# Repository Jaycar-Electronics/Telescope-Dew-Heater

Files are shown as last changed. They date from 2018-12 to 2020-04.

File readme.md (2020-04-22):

# Telescope Dew Heater

This project brings together a few Duinotech Modules and some other parts to create a versatile tool. Inspired by the Dew Heaters used on telescopes, it senses ambient temperature and humidity to control a small heater. Not just for telescopes, but anything that needs to avoid condensation.

## Features include:
- Programmable temperature setpoint
- Temperature target can be set above ambient or dewpoint
- Settings can be saved to EEPROM
- Adjustable failsafe heater output to use if sensors are faulty
- Comprehensive LCD info screen

By making use of as much data as possible, the unit uses no more power than necessary, and can even be run straight from a USB battery pack. It can run a set number of degrees above either dewpoint or ambient temperature. The backlight intensity is also adjustable in code and we've even designed a 3d-printed enclosure that will practically turn it into a professional looking unit.

## Components

| Qty | Code | Description |
| --- | --- | --- |
| 1 | [XC4520](http://jaycar.com.au/p/XC4520) | Temperature and Humidity module |
| 1 | [XC4454](http://jaycar.com.au/p/XC4454) | LCD controller shield |
| 1 | [XC4410](http://jaycar.com.au/p/XC4410) | UNO main board |
| 1 | [RN3440](http://jaycar.com.au/p/RN3440) | 10K Thermistor |
| 1 | [RR0596](http://jaycar.com.au/p/RR0596) | 10K resistor |
| 1 | [RR0572](http://jaycar.com.au/p/RR0572) | 1K resistor |
| 1 | [ZT2468](http://jaycar.com.au/p/ZT2468) | MOSFET |
| 1 | [XC4482](http://jaycar.com.au/p/XC4482) | Proto shield |
| 1 | [WC6028](http://jaycar.com.au/p/WC6028) | Plug-socket lead |
| 1 | [RR3264](http://jaycar.com.au/p/RR3264) | 5W 390 resistor |

The 5W resistor is the heater element. For more power, even a RR3254 15Ohm resistor will happily run off most USB ports (up to 500mA), giving about 1.6 Watts. Another option is to run multiple resistors in parallel to distribute the heat better. For more power, a proper telescope heat band should be used. These usually use an RCA plug, so an RCA socket like PS0250 could be fitted. The circuit uses the VIN pin on the Proto Shield, which cannot handle more than about 1A of current.

## Assembly

Most of the assembly involves adding components to the Proto Shield to give it all the extra functionality it needs. There are effectively three subcircuits on the Proto Shield, one for the thermistor, and another for the humidity sensor and the third to drive a MOSFET for the heater.

The photos below give a guide as to one way to assemble it, but there is a small area (surrounded by a white rectangle) on the Proto Shield which has numerous 5V and GND connections and some short strips, making this an ideal spot to put all this together, especially to make the 5V and GND connections.

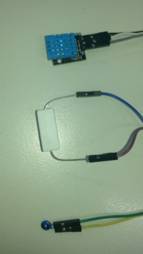
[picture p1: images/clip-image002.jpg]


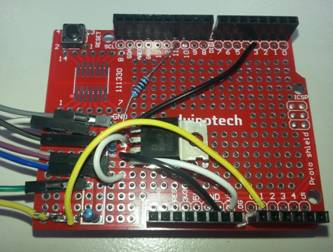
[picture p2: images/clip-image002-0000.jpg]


The thermistor subcircuit looks like this:



The yellow wire above goes to A1 and one of each of the resistor and thermistor, while the green wire goes to 5V, giving a simple voltage divider.



The top black wire connects the S pin of the module to D3.

The MOSFET circuit is the most complex:

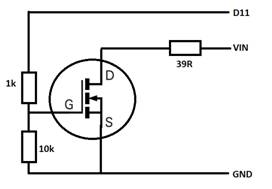
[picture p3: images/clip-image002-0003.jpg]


In the main photo above, the MOSFET's leads are G(gate), D(drain) and S(source), looking from top to bottom. The blue and purple wires run off the board to the 39R resistor, while the two white wires feed the 39R resistor from VIN and the MOSFET drain. The 10k resistor on the left ensures that the MOSFET is off unless the Uno is telling it to be on, while the 1k resistor provides a bit of isolation in case the MOSFET fails.

## Sketch

The code is quite lengthy and uses four different libraries. Luckily, only one of these needs to be installed, all the rest come with the Arduino IDE. The idDHT11 library reads the temperature and humidity sensor and also calculates the dew point. The file is Telescope_Dew_Heater.ino.

Before `setup()`, we initialise all the libraries and global variables. There is also a large array `temps[]` which stores the thermistor temperature conversion. For accuracy, all temperatures are calculated in tenths of a degree.

In setup, the LCD is initialised and values loaded from EEPROM. If these are valid, they are loaded into their respective variables. Because the DHT11 library does its readings in the background, we start a reading now for when we need one in `loop()`. Then we set the backlight intensity.

In `loop()`, the sketch reads all the input, including thermistor, DHT11 temperature, humidity and dew point and keypad. Then it responds to the keypad- if left is pressed, the heater works from the dew point temperature in 'D' mode, if the right button is presses, 'A' mode works with ambient temperature. The setpoint for the heater is set by the up and down buttons between zero and nine degrees. The select button allows the current settings to be saved in EEPROM. How long the button is held down determines what the default heater output will be if a sensor failure is detected.

The temperature target is calculated and the heater output is adjusted by changing the PWM on pin 11, then the current state is output is displayed. If an invalid reading is detected in either sensor, a message is displayed and the heater is set to the default output.

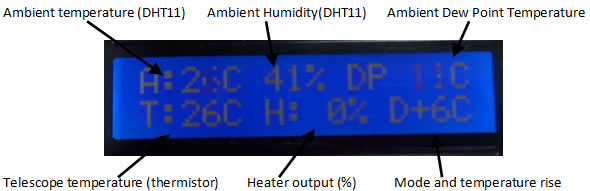
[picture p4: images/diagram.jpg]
screen diagram


In the above image, the ambient temperature is 26 degrees, but the dewpoint temperature is 11 degrees, so the heater will be aiming for dewpoint plus six degrees, or 17 degrees. The actual telescope temperature is 26 degrees, so the heater is off. If the heater was switched to ambient mode by pressing the right button, then the target would be 32 degrees, and the heater would turn fully on. In normal operation, the thermistor should be near, but not quite touching the heater resistor, so that it can quickly respond to changes.

## Improvements

There are a number of places where the heater could be improved, such as changing the default backlight setting to suit your application, or even making it one of the EEPROM settings. If you need more power, the recommended MOSFETs are capable of at least 5A at 24V. In that case, it would be recommended to run the power supply straight to the MOSFET circuit, and then feed VIN back to the UNO board. That way, the small PCB traces don't have to handle such a high current. An old laptop supply or 12V SLA could be options for this. As mentioned near the start, RCA sockets could be used to standardize the connections to those commonly used on heater bands.

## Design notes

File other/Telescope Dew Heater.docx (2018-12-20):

# Telescope Dew Heater

This project brings together a few Duinotech Modules and some other parts to create a versatile tool. Inspired by the Dew Heaters used on telescopes, it senses ambient temperature and humidity to control a small heater. Not just for telescopes, but anything that needs to avoid condensation.

Features include:

- Programmable temperature setpoint
- Temperature target can be set above ambient or dewpoint
- Settings can be saved to EEPROM
- Adjustable failsafe heater output to use if sensors are faulty
- Comprehensive LCD info screen

By making use of as much data as possible, the unit uses no more power than necessary, and can even be run straight from a USB battery pack. It can run a set number of degrees above either dewpoint or ambient temperature. The backlight intensity is also adjustable in code and we’ve even designed a 3d-printed enclosure that will practically turn it into a professional looking unit.

## Parts list:

XC4520 Temperature and Humidity Module

XC4454 LCD and Button Shield

XC4410 Duinotech Uno Board

RN3440 10K Thermistor

RR0596 10K resistors

RR0572 1K resistors

ZT2468 MOSFET (or even a XC4488 MOSFET module)

XC4482 Proto Shield

WC6028 Plug-socket leads

RR3264 5W 39Ohm Resistor

The 5W resistor is the heater element. For more power, even a RR3254 15Ohm resistor will happily run off most USB ports (up to 500mA), giving about 1.6 Watts. Another option is to run multiple resistors in parallel to distribute the heat better. For more power, a proper telescope heat band should be used. These usually use an RCA plug, so an RCA socket like PS0250 could be fitted. The circuit uses the VIN pin on the Proto Shield, which cannot handle more than about 1A of current.

## Assembly:

Most of the assembly involves adding components to the Proto Shield to give it all the extra functionality it needs. There are effectively three subcircuits on the Proto Shield, one for the thermistor, and another for the humidity sensor and the third to drive a MOSFET for the heater.

The photos below give a guide as to one way to assemble it, but there is a small area (surrounded by a white rectangle) on the Proto Shield which has numerous 5V and GND connections and some short strips, making this an ideal spot to put all this together, especially to make the 5V and GND connections.

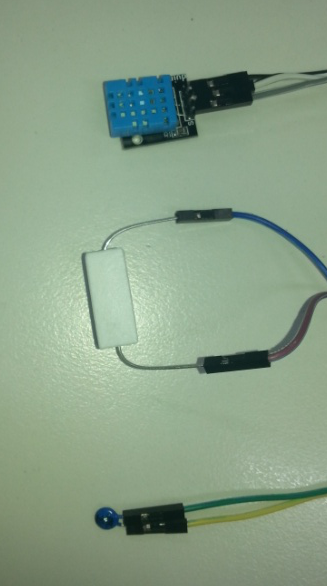
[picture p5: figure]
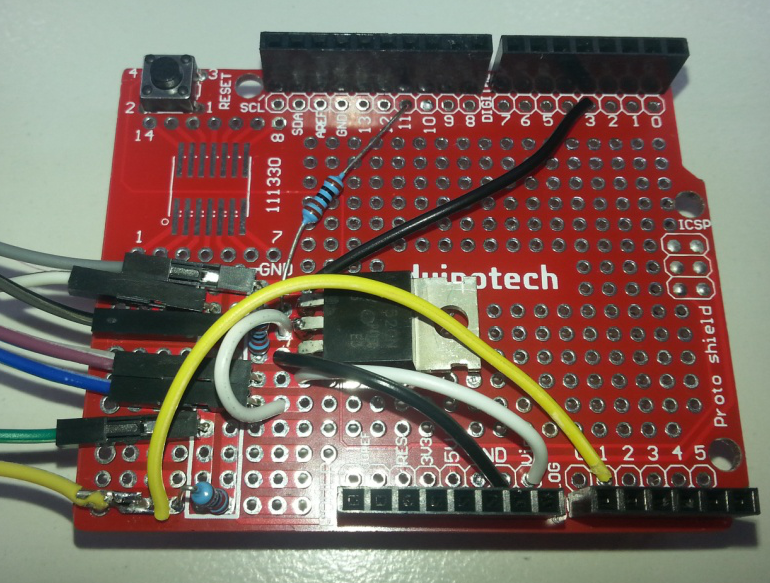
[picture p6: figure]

The thermistor subcircuit looks like this:

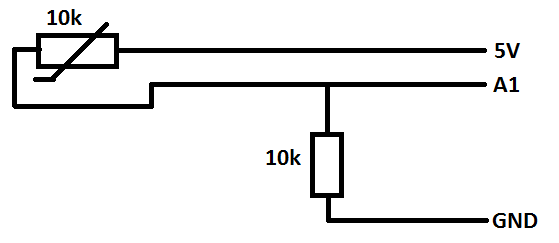
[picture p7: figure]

The yellow wire above goes to A1 and one end of each of the resistor and thermistor, while the green wire goes to 5V, giving a simple voltage divider.

The DHT11 Sensor subcircuit is even simpler:

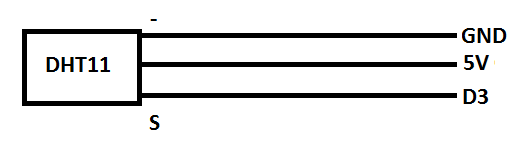
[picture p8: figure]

The top black wire connects the S pin of the module to D3.

The MOSFET circuit is the most complex:

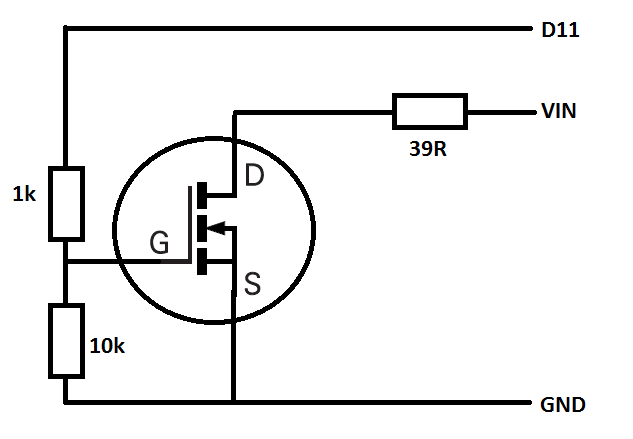
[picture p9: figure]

In the main photo above, the MOSFET’s leads are G(gate), D(drain) and S(source), looking from top to bottom. The blue and purple wires run off the board to the 39R resistor, while the two white wires feed the 39R resistor from VIN and the MOSFET drain. The 10k resistor on the left ensure that the MOSFET is off unless the Uno is telling it to be on, while the 1k resistor provides a bit of isolation in case the MOSFET fails.

## Sketch:

The code is quite lengthy and uses four different libraries. Luckily, only one of these needs to be installed, all the rest come with the Arduino IDE. The idDHT11 library reads the temperature and humidity sensor and also calculates the dew point. The file is Telescope_Dew_Heater.ino.

Before setup(), we initialise all the libraries and global variables. There is also a large array ‘temps[]’ which stores the thermistor temperature conversion. For accuracy, all temperatures are calculated in tenths of a degree.

In setup, the LCD is initialised and values loaded from EEPROM. If these are valid, they are loaded into their respective variables. Because the DHT11 library does its readings in the background, we start a reading now for when we need one in loop(). Then we set the backlight intensity.

In loop(), the sketch reads all the input, including thermistor, DHT11 temperature, humidity and dew point and keypad. Then it responds to the keypad- if left is pressed, the heater works from the dew point temperature in ‘D’ mode, if the right button is presses, ‘A’ mode works with ambient temperature. The setpoint for the heater is set by the up and down buttons between zero and nine degrees. The select button allows the current settings to be saved in EEPROM. How long the button is held down determines what the default heater output will be if a sensor failure is detected.

The temperature target is calculated and the heater output is adjusted by changing the PWM on pin 11, then the current state is output is displayed. If an invalid reading is detected in either sensor, a message is displayed and the heater is set to the default output.

Ambient temperature (DHT11) Ambient Humidity(DHT11) Ambient Dew Point Temperature

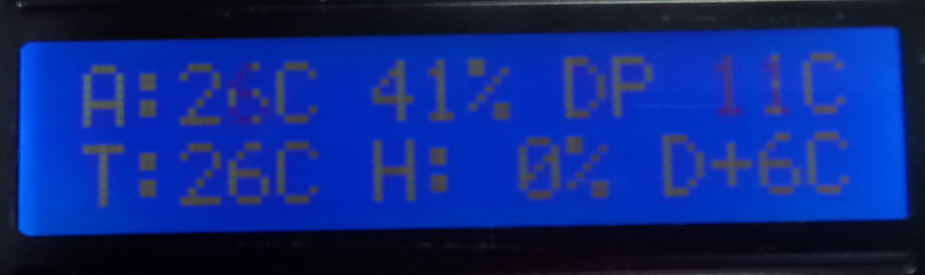
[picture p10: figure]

Telescope temperature (thermistor) Heater output (%) Mode and temperature rise

In the above image, the ambient temperature is 26 degrees, but the dewpoint temperature is 11 degrees, so the heater will be aiming for dewpoint plus six degrees, or 17 degrees. The actual telescope temperature is 26 degrees, so the heater is off. If the heater was switched to ambient mode by pressing the right button, then the target would be 32 degrees, and the heater would turn fully on. In normal operation, the thermistor should be near, but not quite touching the heater resistor, so that it can quickly respond to changes.

## Improvements:

There are a number of places where the heater could be improved, such as changing the default backlight setting to suit your application, or even making it one of the EEPROM settings. If you need more power, the recommended MOSFETs are capable of at least 5A at 24V. In that case, it would be recommended to run the power supply straight to the MOSFET circuit, and then feed VIN back to the UNO board. That way, the small PCB traces don’t have to handle such a high current. An old laptop supply or 12V SLA could be options for this. As mentioned near the start, RCA sockets could be used to standardize the connections to those commonly used on heater bands.

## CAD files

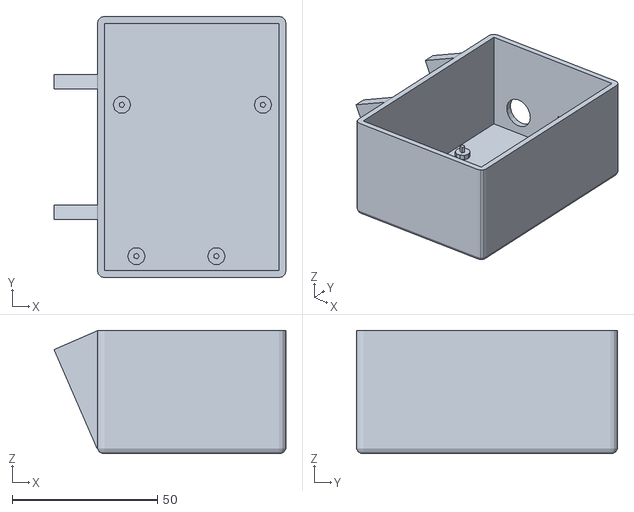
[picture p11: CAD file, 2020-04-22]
stl/Duinotech Box with Legs.stl
79.7 x 89.8 x 42.4

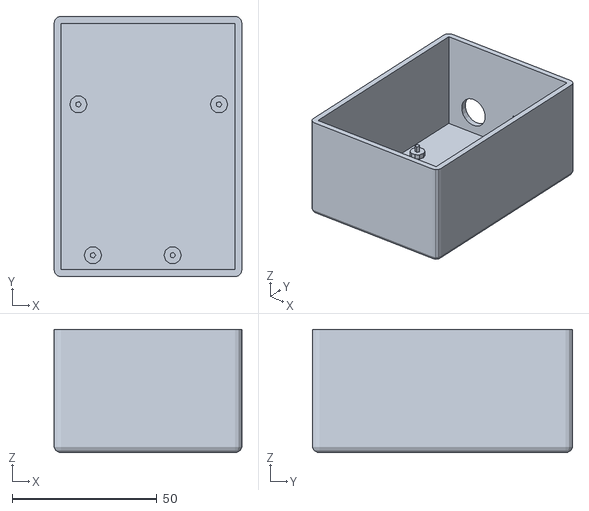
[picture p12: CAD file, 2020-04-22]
stl/Duinotech Box.stl
64.8 x 89.8 x 42.5

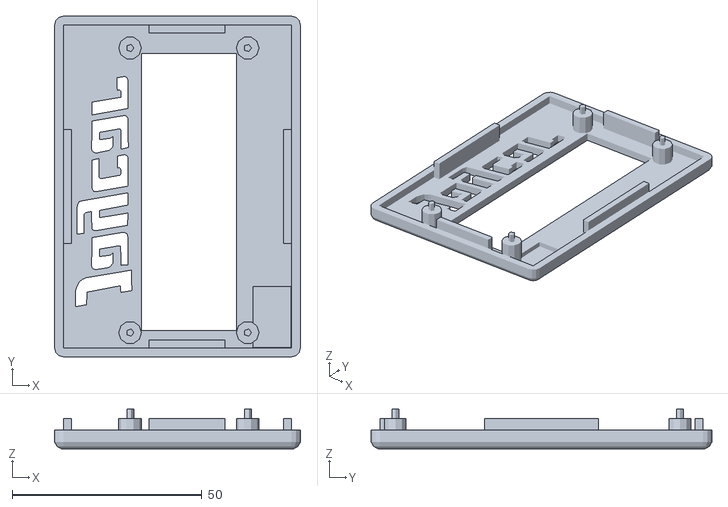
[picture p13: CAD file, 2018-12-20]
stl/Duinotech Box Lid.stl
64.8 x 89.8 x 10.4

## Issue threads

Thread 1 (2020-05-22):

DHT11 fault msg on display

paudel10, 2020-05-22:
Good afternoon, i have brought the iteam for the telescope dew heater project. I assembled it and followed circuitry. However, every time I get dht11 fault msg. I have brought 3 protoshield and 2 dht11 but still getting the same result.
I would appreciate if I can get some guidance for diagnosis. Maybe I'm  doing something wrong as this was my first ever project.
Thank you
Rohit

paudel10, 2020-05-30:
I consulted at jaycars and was told that the problem was with the coding. I'm new to the electronic with no knowledge of coding. It would be a great help if I I could get some guidance or support in this matter.
Thank you
ROHIT

paudel10, 2020-05-30:
Accidentally closed the case

paudel10, 2020-06-07:
bug good first issue help wanted invalid question wontfix

Scobber, 2020-09-18:
Hi @paudel10 I recently fixed this for my brother. Please see my fork which currently works.

[https://github.com/Scobber/Telescope-Dew-Heater](https://github.com/Scobber/Telescope-Dew-Heater)

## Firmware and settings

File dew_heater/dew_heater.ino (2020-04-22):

//pin for buttons
#define KEYPIN A0
//button constants
#define btnRIGHT 6
#define btnUP 5
#define btnDOWN 4
#define btnLEFT 3
#define btnSELECT 2
#define btnNONE (-1)
#define MOSFETPIN 11 //n-channel- PWM capable
#define THERMPIN A1  //10k thermistor and 10k resistor

#include "idDHT11.h"

int idDHT11pin = 3;       //Digital pin for comunications
int idDHT11intNumber = 1; //interrupt number pin3 uses int.1 on uno
void dht11_wrapper();     // must be declared before the lib initialization
idDHT11 DHT11(idDHT11pin, idDHT11intNumber, dht11_wrapper);

void dht11_wrapper()
{
  DHT11.isrCallback();
}

#include <LiquidCrystal.h>
LiquidCrystal lcd(8, 9, 4, 5, 6, 7); //for XC4454 LCD Shield LiquidCrystal lcd(RS, E, b4, b5, b6, b7);
//change normal backlight intensity here:
#define BACKLIGHTINTENSITY 40
#define BACKLIGHTPWMPIN 10

#include <avr/pgmspace.h>
// Big lookup Table (approx 750 entries), subtract 238 from ADC reading to start at 0*C. Entries in 10ths of degree i.e. 242 = 24.2*C Covers 0*C to 150*C For 10k resistor/10k thermistor voltage divider w/ therm on the + side.
const int temps[] PROGMEM = {0, 1, 2, 3, 4, 6, 7, 8, 9, 10, 11, 12, 13, 14, 15, 16, 17, 18, 19, 20, 21, 22, 24, 25, 26, 27, 28, 29, 30, 31, 32, 33, 34, 35, 36, 37, 38, 39, 40, 41, 42, 43, 44, 45, 46, 47, 48, 49, 50, 51, 52, 53, 54, 55, 56, 57, 58, 59, 60, 61, 62, 63, 64, 65, 66, 67, 68, 68, 69, 70, 71, 72, 73, 74, 75, 76, 77, 78, 79, 80, 81, 82, 83, 84, 85, 86, 87, 88, 88, 89, 90, 91, 92, 93, 94, 95, 96, 97, 98, 99, 100, 101, 102, 102, 103, 104, 105, 106, 107, 108, 109, 110, 111, 112, 113, 114, 114, 115, 116, 117, 118, 119, 120, 121, 122, 123, 124, 124, 125, 126, 127, 128, 129, 130, 131, 132, 133, 134, 134, 135, 136, 137, 138, 139, 140, 141, 142, 143, 143, 144, 145, 146, 147, 148, 149, 150, 151, 151, 152, 153, 154, 155, 156, 157, 158, 159, 159, 160, 161, 162, 163, 164, 165, 166, 167, 167, 168, 169, 170, 171, 172, 173, 174, 175, 175, 176, 177, 178, 179, 180, 181, 182, 182, 183, 184, 185, 186, 187, 188, 189, 190, 190, 191, 192, 193, 194, 195, 196, 197, 197, 198, 199, 200, 201, 202, 203, 204, 205, 205, 206, 207, 208, 209, 210, 211, 212, 212, 213, 214, 215, 216, 217, 218, 219, 220, 220, 221, 222, 223, 224, 225, 226, 227, 228, 228, 229, 230, 231, 232, 233, 234, 235, 235, 236, 237, 238, 239, 240, 241, 242, 243, 243, 244, 245, 246, 247, 248, 249, 250, 251, 252, 252, 253, 254, 255, 256, 257, 258, 259, 260, 260, 261, 262, 263, 264, 265, 266, 267, 268, 269, 269, 270, 271, 272, 273, 274, 275, 276, 277, 278, 279, 279, 280, 281, 282, 283, 284, 285, 286, 287, 288, 289, 289, 290, 291, 292, 293, 294, 295, 296, 297, 298, 299, 300, 301, 301, 302, 303, 304, 305, 306, 307, 308, 309, 310, 311, 312, 313, 314, 315, 315, 316, 317, 318, 319, 320, 321, 322, 323, 324, 325, 326, 327, 328, 329, 330, 331, 332, 333, 334, 335, 335, 336, 337, 338, 339, 340, 341, 342, 343, 344, 345, 346, 347, 348, 349, 350, 351, 352, 353, 354, 355, 356, 357, 358, 359, 360, 361, 362, 363, 364, 365, 366, 367, 368, 369, 370, 371, 372, 373, 374, 375, 376, 377, 378, 379, 380, 381, 382, 383, 384, 385, 386, 387, 388, 389, 390, 392, 393, 394, 395, 396, 397, 398, 399, 400, 401, 402, 403, 404, 405, 406, 407, 408, 410, 411, 412, 413, 414, 415, 416, 417, 418, 419, 420, 422, 423, 424, 425, 426, 427, 428, 429, 430, 432, 433, 434, 435, 436, 437, 438, 439, 441, 442, 443, 444, 445, 446, 448, 449, 450, 451, 452, 453, 455, 456, 457, 458, 459, 460, 462, 463, 464, 465, 466, 468, 469, 470, 471, 472, 474, 475, 476, 477, 479, 480, 481, 482, 484, 485, 486, 487, 489, 490, 491, 492, 494, 495, 496, 498, 499, 500, 501, 503, 504, 505, 507, 508, 509, 511, 512, 513, 515, 516, 517, 519, 520, 521, 523, 524, 525, 527, 528, 530, 531, 532, 534, 535, 537, 538, 539, 541, 542, 544, 545, 547, 548, 550, 551, 552, 554, 555, 557, 558, 560, 561, 563, 564, 566, 567, 569, 570, 572, 574, 575, 577, 578, 580, 581, 583, 585, 586, 588, 589, 591, 593, 594, 596, 598, 599, 601, 603, 604, 606, 608, 609, 611, 613, 614, 616, 618, 620, 621, 623, 625, 627, 628, 630, 632, 634, 636, 638, 639, 641, 643, 645, 647, 649, 651, 653, 654, 656, 658, 660, 662, 664, 666, 668, 670, 672, 674, 676, 678, 680, 683, 685, 687, 689, 691, 693, 695, 697, 700, 702, 704, 706, 708, 711, 713, 715, 718, 720, 722, 725, 727, 729, 732, 734, 737, 739, 741, 744, 746, 749, 752, 754, 757, 759, 762, 764, 767, 770, 773, 775, 778, 781, 784, 786, 789, 792, 795, 798, 801, 804, 807, 810, 813, 816, 819, 822, 825, 829, 832, 835, 838, 842, 845, 848, 852, 855, 859, 862, 866, 869, 873, 877, 881, 884, 888, 892, 896, 900, 904, 908, 912, 916, 920, 925, 929, 933, 938, 942, 947, 952, 956, 961, 966, 971, 976, 981, 986, 991, 997, 1002, 1007, 1013, 1019, 1024, 1030, 1036, 1042, 1049, 1055, 1061, 1068, 1075, 1082, 1088, 1096, 1103, 1110, 1118, 1126, 1134, 1142, 1150, 1159, 1168, 1177, 1186, 1196, 1206, 1216, 1226, 1237, 1248, 1260, 1272, 1284, 1297, 1310, 1324, 1338, 1353, 1369, 1385, 1402, 1420, 1439, 1459, 1480, 1502};

//for saving startup defaults to eeprom
#include <EEPROM.h>
//eeprom addresses for variables
#define OFFSETMODEADDRESS 0
#define TEMPOFFSETADDRESS 1
#define PWMOUTPUTDEFAULTADDRESS 2

byte DHTdat[5];              //data from DHT11 sensor to be stored in 0.1 humidity% 2.3 degrees C
int tempoffset = 5;          //setpoint offset above dewpoint
byte offsetmode = 'D';       //default to dew point offset
int ambtemp, ambhum, dptemp; //all measured in 1/10's
int pwmoutputdefault = 52;   //10%

void setup()
{
  Serial.begin(9600); //if needed for debugging
  lcd.begin(16, 2);
  lcd.clear();
  int value = EEPROM.read(OFFSETMODEADDRESS);
  if ((value == 'D') || (value == 'A'))
  { //valid eeprom values found
    offsetmode = value;
    tempoffset = EEPROM.read(TEMPOFFSETADDRESS);
    pwmoutputdefault = EEPROM.read(PWMOUTPUTDEFAULTADDRESS);
    lcd.setCursor(0, 0);
    lcd.print("Load EEPROM OK  ");
  }
  else
  {
    lcd.setCursor(0, 0);
    lcd.print("Invalid EEPROM  ");
  }
  DHT11.acquire(); //start 1st conversion
  delay(500);      //and wait a bit for conversion to finish
  analogWrite(BACKLIGHTPWMPIN, BACKLIGHTINTENSITY);
}

void loop()
{
  int teletemp;       //telescope temperature
  int thermerror = 0; // flag for thermistor error
  teletemp = analogRead(THERMPIN);
  if ((teletemp == 0) | (teletemp > 950))
  {
    thermerror = thermerror | 1;
  } //thermistor error detected
  teletemp = teletemp - 238;
  if (teletemp < 0)
  {
    teletemp = 0;
  } //lookup table won't work if index<0
  teletemp = pgm_read_word(&temps[teletemp]);

  if (DHT11.getStatus() == IDDHTLIB_OK)
  {
    ambtemp = DHT11.getCelsius() * 10;
    ambhum = DHT11.getHumidity() * 10;
    dptemp = DHT11.getDewPointSlow() * 10;
  }
  else
  {
    thermerror = thermerror | 2;
  }

  int key;
  key = read_LCD_buttons();
  if (key == btnLEFT)
  {
    offsetmode = 'D';
  } //offset from dewpoint
  if (key == btnRIGHT)
  {
    offsetmode = 'A';
  } //offset from ambient
  if (key == btnUP)
  {
    tempoffset++;
    if (tempoffset > 9)
    {
      tempoffset = 9;
    }
  }
  if (key == btnDOWN)
  {
    tempoffset--;
    if (tempoffset < 0)
    {
      tempoffset = 0;
    }
  }
  if (key == btnSELECT)
  {
    savetoeeprom();
  } //save to eeprom (load happens on boot)

  int temptarget;
  if (offsetmode == 'D')
  {
    temptarget = dptemp + tempoffset * 10;
  }
  else
  {
    temptarget = ambtemp + tempoffset * 10; //default to (higher) ambient temp if anything but 'D'
  }

  int pwmoutput;
  pwmoutput = constrain(map(temptarget - teletemp, -10, 10, 0, 255), 0, 255);
  if (thermerror)
  {
    pwmoutput = pwmoutputdefault;
  }
  analogWrite(MOSFETPIN, pwmoutput);

  lcd.setCursor(0, 0);
  switch (thermerror)
  {
  case 0:
    LCDtopline();
    break;
  case 1:
    lcd.print("Thermistor fault");
    break;
  case 2:
    lcd.print("DHT11 fault     ");
    break;
  case 3:
    lcd.print("Thrm & DHT11 flt");
    break;
  default:
    lcd.print("Thrm & DHT11 flt");
    break;
  }

  lcd.setCursor(0, 1);
  lcd.print("T:");
  if (teletemp > 99)
  {
    lcd.write((teletemp / 100) % 10 + '0');
  }
  else
  {
    lcd.write(' ');
  }
  lcd.write((teletemp / 10) % 10 + '0');
  lcd.print("C H:");
  pwmoutput = (pwmoutput * 39) / 100; //scale to %
  if (pwmoutput > 9)
  {
    lcd.write((pwmoutput / 10) % 10 + '0');
  }
  else
  {
    lcd.write(' ');
  }
  lcd.write((pwmoutput) % 10 + '0');
  lcd.print("% ");
  lcd.write(offsetmode);
  lcd.print("+");
  lcd.write((tempoffset) % 10 + '0');
  lcd.print("C");
  DHT11.acquire(); //start next conversion
  delay(500);
}

int read_LCD_buttons()
{
  int adc_key_in = 0;
  adc_key_in = analogRead(KEYPIN);           // read the value from the sensor
  delay(5);                                  //switch debounce delay. Increase this delay if incorrect switch selections are returned.
  int k = (analogRead(KEYPIN) - adc_key_in); //gives the button a slight range to allow for a little contact resistance noise
  if (5 < abs(k))
    return btnNONE; // double checks the keypress. If the two readings are not equal +/-k value after debounce delay, it tries again.
  // my buttons when read are centered at these valies: 0, 144, 329, 504, 741
  // we add approx 50 to those values and check to see if we are close
  if (adc_key_in > 1000)
    return btnNONE; // We make this the 1st option for speed reasons since it will be the most likely result
  if (adc_key_in < 50)
    return btnRIGHT;
  if (adc_key_in < 195)
    return btnUP;
  if (adc_key_in < 380)
    return btnDOWN;
  if (adc_key_in < 555)
    return btnLEFT;
  if (adc_key_in < 790)
    return btnSELECT;
  return btnNONE; // when all others fail, return this...
}

void LCDtopline()
{
  lcd.print("A:");
  if (ambtemp > 99)
  {
    lcd.write((ambtemp / 100) % 10 + '0');
  }
  else
  {
    lcd.write(' ');
  }
  lcd.write((ambtemp / 10) % 10 + '0');
  lcd.print("C ");
  if (ambhum > 99)
  {
    lcd.write((ambhum / 100) % 10 + '0');
  }
  else
  {
    lcd.write(' ');
  }
  lcd.write((ambhum / 10) % 10 + '0');
  lcd.print("% DP ");
  if (dptemp > 99)
  {
    lcd.write((dptemp / 100) % 10 + '0');
  }
  else
  {
    lcd.write(' ');
  }
  lcd.write((dptemp / 10) % 10 + '0');
  lcd.print("C ");
}

void savetoeeprom()
{
  int htr = 0;
  int key;
  analogWrite(MOSFETPIN, 0); //shut down heater in case button is stuck
  lcd.setCursor(0, 0);
  lcd.print("Choose value for");
  lcd.setCursor(0, 1);
  lcd.print("Heater backup:");
  while (read_LCD_buttons() == btnSELECT)
  { //cycle while select held down
    htr = htr + 5;
    if (htr > 99)
    {
      htr = 0;
    }
    lcd.setCursor(14, 1);
    if (htr > 9)
    {
      lcd.write((htr / 10) % 10 + '0');
    }
    else
    {
      lcd.write(' ');
    }
    lcd.write((htr) % 10 + '0');
    delay(500);
  }
  lcd.setCursor(0, 0);
  lcd.print("Saving EEPROM...");
  EEPROM.write(OFFSETMODEADDRESS, offsetmode);
  EEPROM.write(TEMPOFFSETADDRESS, tempoffset);
  EEPROM.write(PWMOUTPUTDEFAULTADDRESS, (htr + 1) * 100 / 39);
  delay(500);
}
